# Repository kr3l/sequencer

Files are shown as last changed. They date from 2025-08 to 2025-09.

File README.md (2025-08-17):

ESP32 + TL074

the TL074 opamp is fed with -12 and +12V

GPIO25 -> pin3 of opamp
5.6kOhm + 1kOhm precision trimmer between pin 1 and 2 of opamp (feedback resistor)
10kOhm resistor between pin 2 and GND
-> opamp gain 1 + 5.6/10 -> 1.56
-> output max goes from 3.3V to 5.148V

100nF between pin 1 and GND

precision trimmer calibrated so the max outputted voltage on DAC results in exactly 5V

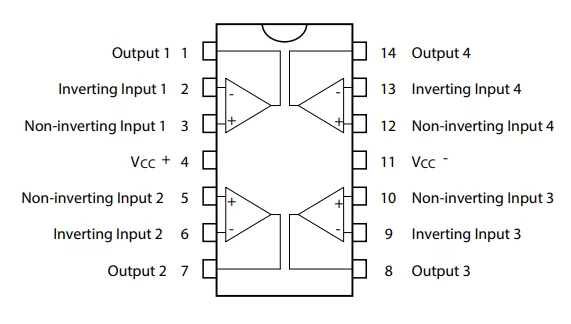
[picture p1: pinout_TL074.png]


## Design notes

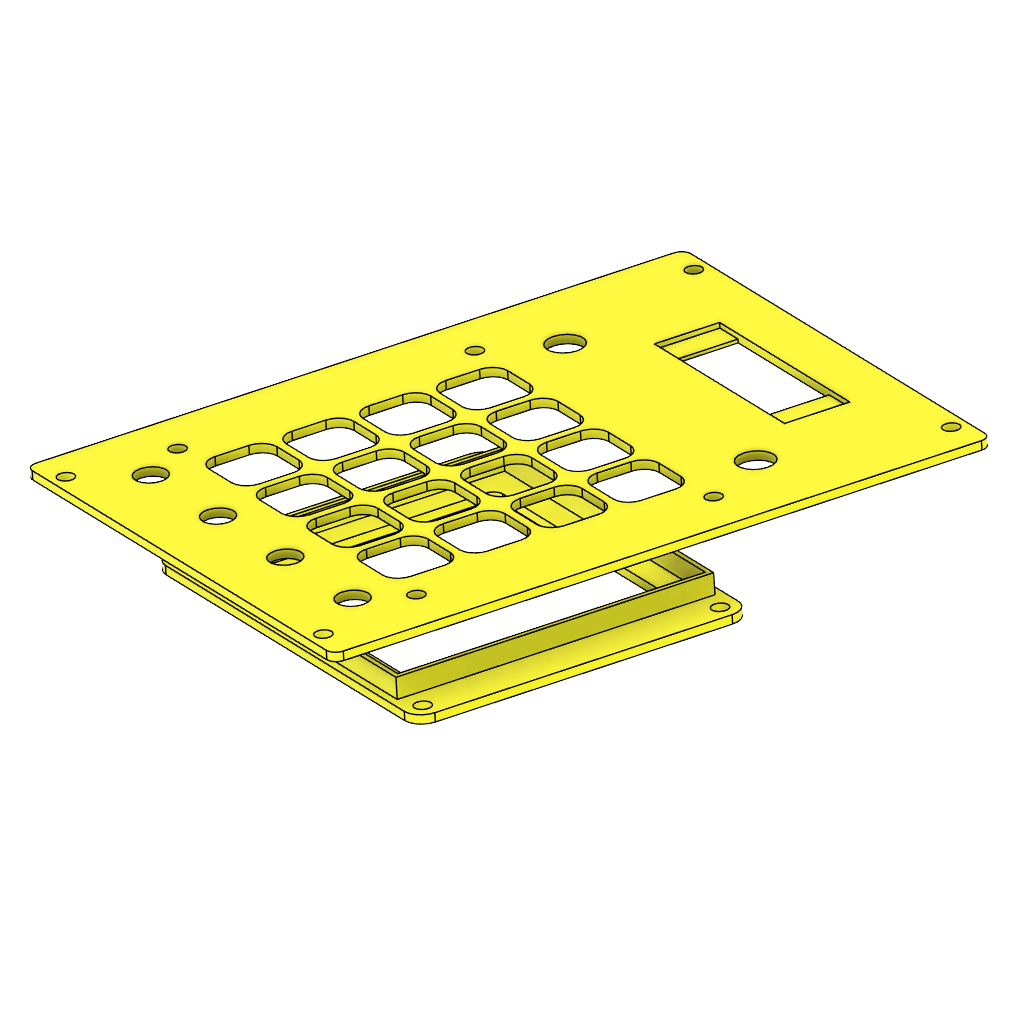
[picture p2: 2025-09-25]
cad/sequencer-neotrellis-eurorack v12.png

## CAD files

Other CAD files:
cad/sequencer-neotrellis v3.f3z
cad/sequencer-neotrellis v7.f3z
cad/sequencer-neotrellis-eurorack v11.f3z

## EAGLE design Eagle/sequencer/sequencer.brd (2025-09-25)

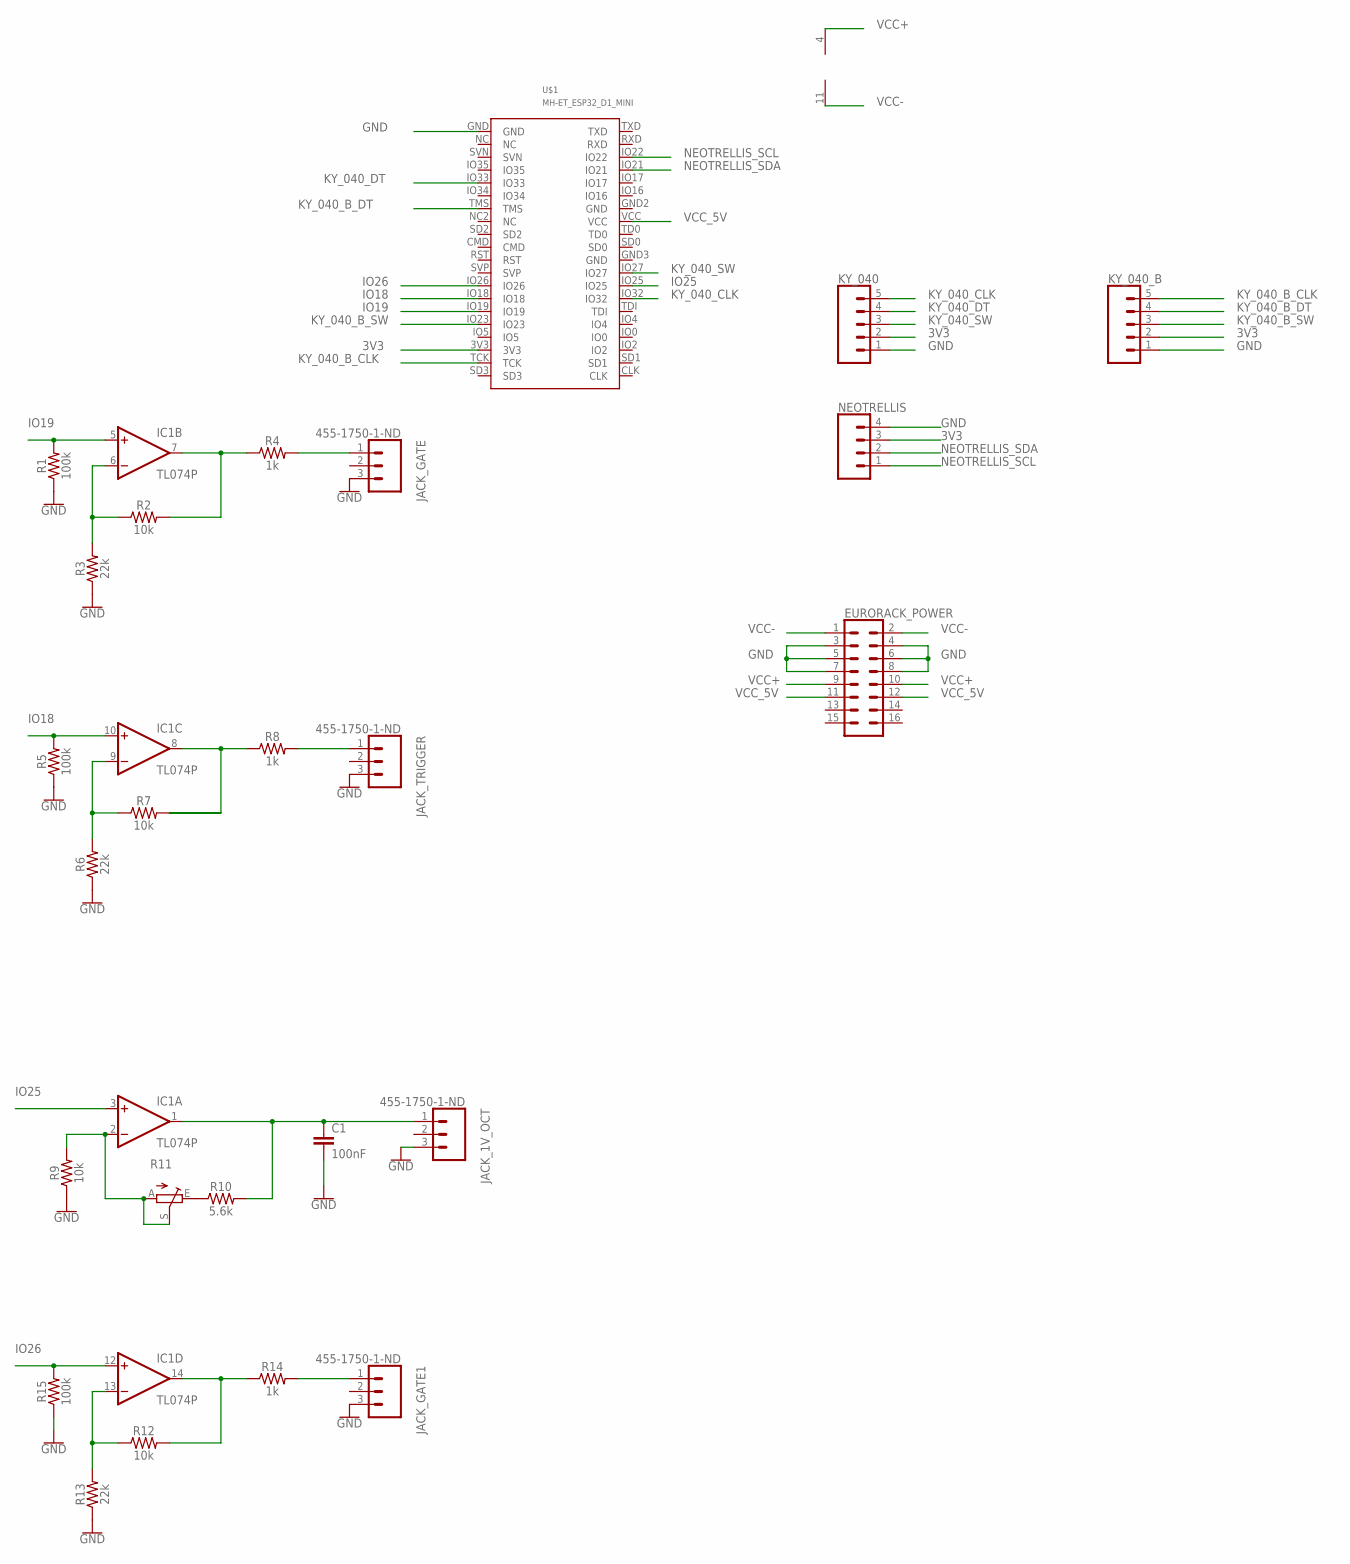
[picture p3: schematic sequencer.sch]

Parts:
C1: 100nF; C050-035X075
EURORACK_POWER: CONN_08X2_SHROUD; 2X8-SHROUDED_LOCK
IC1: TL074P; DIL14
JACK_1V_OCT: 455-1750-1-ND; 1X03
JACK_GATE, JACK_GATE1: 455-1750-1-ND; 1X03
JACK_TRIGGER: 455-1750-1-ND; 1X03
KY_040, KY_040_B: CONN_05; 1X05
NEOTRELLIS: CONN_04PTH; 1X04
R1, R5, R15: 100k; AXIAL-0.1
R2, R7, R9, R12: 10k; AXIAL-0.1
R3, R6, R13: 22k; AXIAL-0.1
R4, R8, R14: 1k; AXIAL-0.1
R10: 5.6k; AXIAL-0.1
R11: TRIM_EU-B64W; B64W
U$1: MH-ET_ESP32_D1_MINI

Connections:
3V3: KY_040.2, KY_040_B.2, NEOTRELLIS.3, U$1.3V3
GND: C1.2, EURORACK_POWER.3, EURORACK_POWER.4, EURORACK_POWER.5, EURORACK_POWER.6, EURORACK_POWER.7, EURORACK_POWER.8, JACK_1V_OCT.3, JACK_GATE.3, JACK_GATE1.3, JACK_TRIGGER.3, KY_040.1, KY_040_B.1, NEOTRELLIS.4, R1.P$1 (1), R3.P$1 (1), R5.P$1 (1), R6.P$1 (1), R9.P$1 (1), R13.P$1 (1), R15.P$1 (1), U$1.GND
IO18: IC1.10 (+IN), R5.P$2 (2), U$1.IO18
IO19: IC1.5 (+IN), R1.P$2 (2), U$1.IO19
IO25: IC1.3 (+IN), U$1.IO25
IO26: IC1.12 (+IN), R15.P$2 (2), U$1.IO26
KY_040_B_CLK: KY_040_B.5, U$1.TCK
KY_040_B_DT: KY_040_B.4, U$1.TMS
KY_040_B_SW: KY_040_B.3, U$1.IO23
KY_040_CLK: KY_040.5, U$1.IO32
KY_040_DT: KY_040.4, U$1.IO33
KY_040_SW: KY_040.3, U$1.IO27
unnamed: IC1.6 (-IN), R2.P$1 (1), R3.P$2 (2)
unnamed: IC1.7 (OUT), R2.P$2 (2), R4.P$1 (1)
unnamed: JACK_GATE.1, R4.P$2 (2)
unnamed: IC1.9 (-IN), R6.P$2 (2), R7.P$1 (1)
unnamed: IC1.8 (OUT), R8.P$1 (1)
unnamed: JACK_TRIGGER.1, R8.P$2 (2)
unnamed: IC1.13 (-IN), R12.P$1 (1), R13.P$2 (2)
unnamed: C1.1, IC1.1 (OUT), JACK_1V_OCT.1, R10.P$2 (2)
unnamed: R10.P$1 (1), R11.E
unnamed: IC1.2 (-IN), R9.P$2 (2), R11.A, R11.S
unnamed: IC1.14 (OUT), R12.P$2 (2), R14.P$1 (1)
unnamed: JACK_GATE1.1, R14.P$2 (2)
NEOTRELLIS_SCL: NEOTRELLIS.1, U$1.IO22
NEOTRELLIS_SDA: NEOTRELLIS.2, U$1.IO21
VCC+: EURORACK_POWER.9, EURORACK_POWER.10, IC1.4 (V+)
VCC-: EURORACK_POWER.1, EURORACK_POWER.2, IC1.11 (V-)
VCC_5V: EURORACK_POWER.11, EURORACK_POWER.12, U$1.VCC

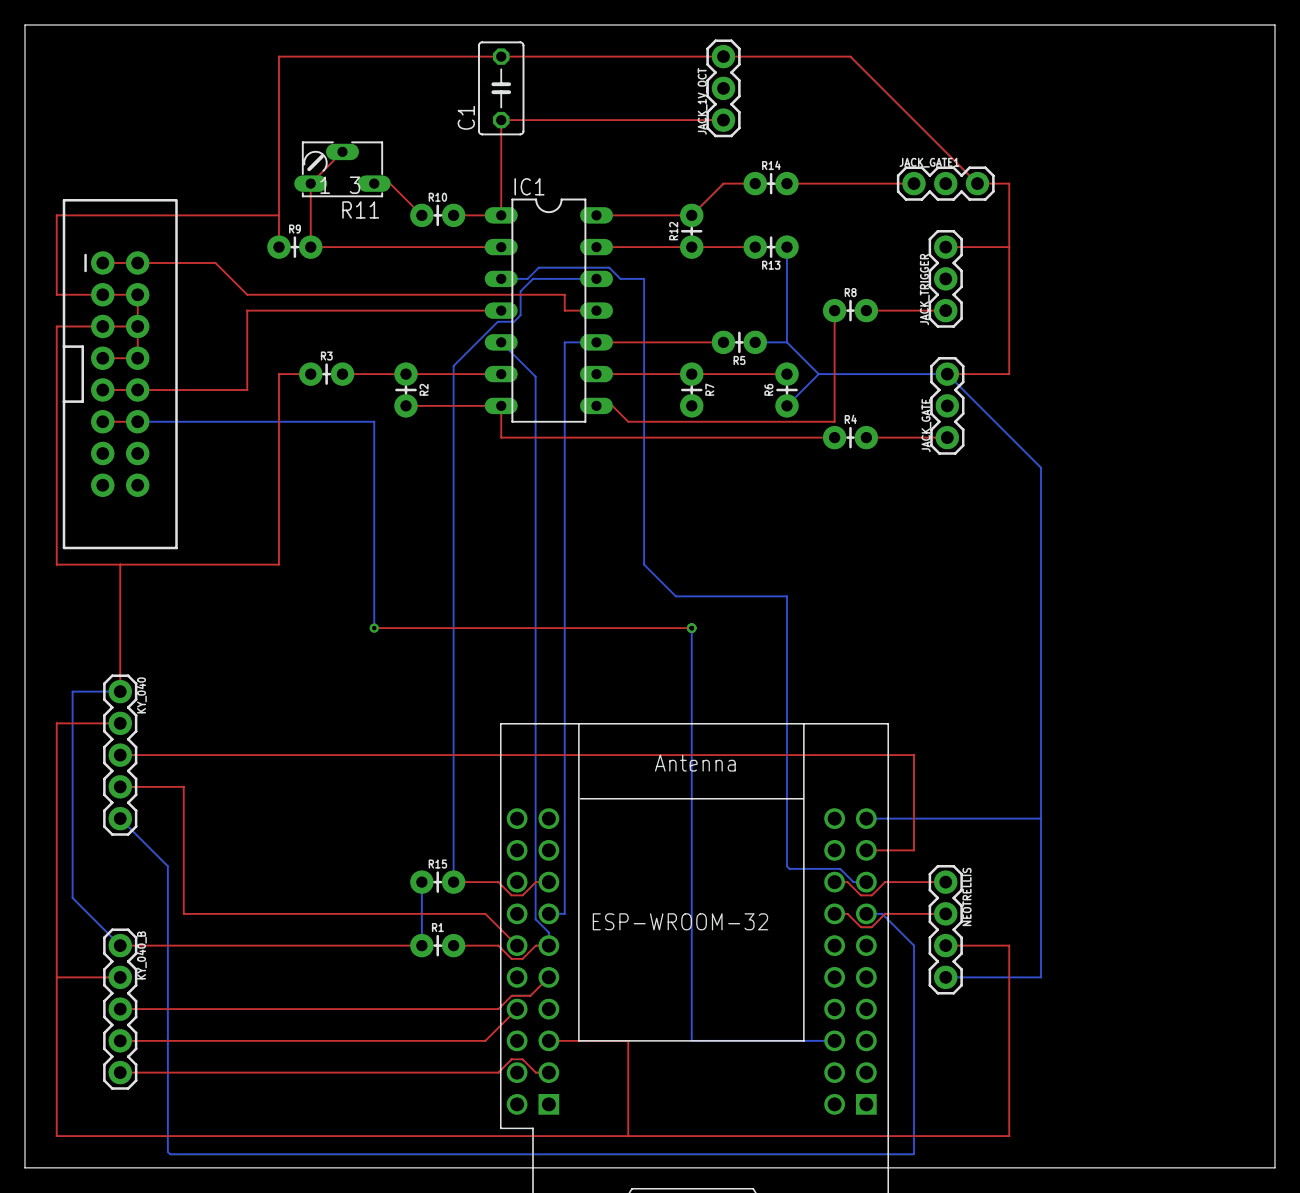
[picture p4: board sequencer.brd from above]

Board: 2 copper layers, 100.0 x 91.4 mm, 26 parts (0 on the bottom side), 29 nets.

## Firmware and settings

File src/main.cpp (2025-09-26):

#include <Arduino.h>
#include <Wire.h>
#include "NotePlayer.h"
#include "TrellisPad.h"
#include "Player.h"
#include "Melodies.h"
#include <ESP32Encoder.h>
#include <Preferences.h>

// OLED libs
#include <Adafruit_GFX.h>
#include <Adafruit_SSD1306.h>

// OLED pins
#define OLED_SDA SDA
#define OLED_SCL SCL
#define OLED_RST -1
#define SCREEN_WIDTH 128
#define SCREEN_HEIGHT 32

Preferences prefs;

// Create an Adafruit_SSD1306 object called display.
Adafruit_SSD1306 display(SCREEN_WIDTH, SCREEN_HEIGHT, &Wire, OLED_RST);

bool isProgramming[16];

//const int potPin = 36; // GPIO36 = ADC1_CH0 on ESP32 D1 mini
const int gatePin = 19;
const int triggerPin = 18;

NotePlayer notePlayer = NotePlayer(25); // GPIO25 supports DAC on ESP32
TrellisPad trellisPad = TrellisPad();
Player player = Player(&trellisPad, &notePlayer, 12, gatePin, triggerPin);

ESP32Encoder knobLeft;
ESP32Encoder knobRight;

enum EditMode {
    MODE_PITCH,
    MODE_DUTY,
    MODE_VELOCITY,
    MODE_STEPCOUNT,
};
const u_int8_t NUM_MODES = 4;
EditMode currentMode = MODE_PITCH;
EditMode previousMode = MODE_DUTY; // just so we trigger a change initially

// the last row of pads on neotrellis are reserved for functions
// and are not playable pads
int playButtonNumber = 12;
int modeButtonNumber = 13;

unsigned long minSlotDurationMs = 50;
unsigned long maxSlotDurationMs = 4000;

void setupDisplay() {
  // The parameters set as false ensure that the library doesn’t 
  // use the default I2C pins and use the pins defined in the code (GPIO 4 and GPIO 15).
  if (!display.begin(SSD1306_SWITCHCAPVCC, 0x3c, false, false)) {
    // address 0x3C for 128x32
    Serial.println(F("SSD1306 allocation failed"));
    for(;;); // Don't proceed, loop forever
  }
  // flip 180deg
  display.setRotation(2);
  display.clearDisplay();
  display.setTextColor(WHITE);
  display.setTextSize(2);
  display.setCursor(0,0);
  display.print("SEQUENCER");
  display.display();
}

int getKnobLeftCount() {
  int count = -(int32_t)knobLeft.getCount();
  return constrain(count, 0, 256);
}

int getKnobRightCount() {
  int count = -(int32_t)knobRight.getCount();
  return constrain(count, 0, 256);
}

void onLongPress(int x, int y) {
  int idx = y * 4 + x;
  if (player.steps[idx].isProgramming) {
    Serial.print("Stop Programming slot ");
  } else {
    Serial.print("Start Programming slot ");
  }
  Serial.println(idx);
  // Enter or leave programming mode (start blinking)
  player.steps[idx].isProgramming = !player.steps[idx].isProgramming;
  trellisPad.setBlinking(idx, player.steps[idx].isProgramming);
  trellisPad.lastBlink[idx] = millis();
  trellisPad.ledState[idx] = false;  // start off
}

void savePotToStep(int idx) {
    // short press to confirm writing pot value to slot idx
    int raw = getKnobLeftCount(); // read raw ADC value
    // Map raw value (0–4095) to percentage
    float dacOut =  ((float)raw / 255.0f) * notePlayer.dacOutMax;

    // autotune to nearest note
    dacOut = notePlayer.autotune(dacOut);

    player.steps[idx].programmedValue = dacOut;
    player.steps[idx].isProgramming = false;
    trellisPad.setBlinking(idx, false);
    Serial.print("Programmed slot ");
    Serial.println(idx);
    Serial.print("to value ");
    Serial.println(dacOut);
    trellisPad.trellis->pixels.setPixelColor(idx, 0x000000); // off
}

void onShortPress(int x, int y) {
  int idx = y * 4 + x;
  Serial.print("Short press detected on button ");
  Serial.println(idx);

  if (idx == modeButtonNumber) {
    currentMode = (EditMode)((currentMode + 1) % NUM_MODES);
    Serial.print("Set mode=");
    Serial.println(currentMode);
  }
  if (idx == playButtonNumber) {
    player.isPlayingSequence = !player.isPlayingSequence;
    
    if (player.isPlayingSequence) {
      player.playSlot(0);
      Serial.println("Play!");
      trellisPad.trellis->pixels.setPixelColor(playButtonNumber, 0xff1493); // on
    } else {
      Serial.println("Stop!");
      trellisPad.trellis->pixels.setPixelColor(playButtonNumber, 0x000000); // off
    }
  }

  if (idx >= player.numberOfPlayableSteps) {
    return;
  }

  if (player.steps[idx].isProgramming) {
    savePotToStep(idx);
  } else {
    // short press to turn gate on or off
    player.steps[idx].gateOn = !player.steps[idx].gateOn;
    // TODO: light led too, but dimmed
    // short press to request play note of slox idx
    //player.playSlot(idx);
  }
}


void saveData() {
  prefs.begin("storage", false);

  // read first so we can check if anything really changed
  float pitchR[16] = {0};
  bool gateOnR[16] = {true};
  uint8_t dutyR[16] = {100};
  size_t pitchBytesRead = prefs.getBytes("pitch", pitchR, sizeof(pitchR));
  size_t gateOnBytesRead = prefs.getBytes("gateOn", gateOnR, sizeof(gateOnR));
  size_t dutyBytesRead = prefs.getBytes("duty", dutyR, sizeof(dutyR));

  unsigned long stepDurationMsR = prefs.getULong("stepDurationMs", 0);
  int stepCountR = prefs.getInt("stepCount", 12);


  float pitch[16] = {0};
  bool gateOn[16] = {true};
  uint8_t duty[16] = {100};
  bool pitchChanged = (pitchBytesRead != sizeof(pitchR));
  bool gateOnChanged = (gateOnBytesRead != sizeof(gateOn));
  bool dutyChanged = (dutyBytesRead != sizeof(dutyR));
  for (int i = 0; i < 16; i += 1) {
    pitch[i] = player.steps[i].programmedValue;
    if (pitch[i] != pitchR[i]) {
      pitchChanged = true;
    }
    gateOn[i] = player.steps[i].gateOn;
    if (gateOn[i] != gateOnR[i]) {
      gateOnChanged = true;
    }
    duty[i] = player.steps[i].duty;
    if (duty[i] != dutyR[i]) {
      dutyChanged = true;
    }
  }

  // compare read version with what we want to write. Bail if exactly the same


  if (pitchChanged) {
    prefs.putBytes("pitch", pitch, sizeof(pitch));
    Serial.println("Pitch saved");
  }
  if (gateOnChanged) {
    prefs.putBytes("gateOn", gateOn, sizeof(gateOn));
    Serial.println("GateOn saved");
  }
  if (dutyChanged) {
    prefs.putBytes("duty", duty, sizeof(duty));
    Serial.println("Duty saved");
  }
  if (stepDurationMsR != player.stepDurationMs) {
    prefs.putULong("stepDurationMs", player.stepDurationMs);
    Serial.println("Tempo saved");
  }
  if (stepCountR != player.numberOfPlayableSteps) {
    prefs.putInt("stepCount", player.numberOfPlayableSteps);
    Serial.println("Step count saved");
  }
  
  prefs.end();
}

void loadData() {
  prefs.begin("storage", true);

  float pitch[16] = {0};
  bool gateOn[16] = {true};
  uint8_t duty[16] = {100};
  size_t pitchBytesRead = prefs.getBytes("pitch", pitch, sizeof(pitch));
  size_t gateOnBytesRead = prefs.getBytes("gateOn", gateOn, sizeof(gateOn));
  size_t dutyBytesRead = prefs.getBytes("duty", duty, sizeof(duty));
  unsigned long stepDurationMsR = prefs.getULong("stepDurationMs", player.stepDurationMs);
  int stepCountR = prefs.getInt("stepCount", 12);

  if (
    (pitchBytesRead != sizeof(pitch))
    || (gateOnBytesRead != sizeof(gateOn))
    || (dutyBytesRead != sizeof(duty))
  ) {
    prefs.end();
     Serial.println("No prefs found");
    return;
  }

  for (int i = 0; i < 16; i += 1) {
    player.steps[i].programmedValue = pitch[i];
    player.steps[i].gateOn = gateOn[i];
    player.steps[i].duty = duty[i];
  }
  player.stepDurationMs = stepDurationMsR;
  player.numberOfPlayableSteps = stepCountR;

  prefs.end();
  Serial.println("Prefs loaded");
}

void setup() {
  Serial.begin(115200);

  Serial.print("Using I2C at SDA=");
  Serial.print(SDA);
  Serial.print(", SCL=");
  Serial.println(SCL);
  Wire.begin(SDA, SCL);
  Wire.setClock(100000);

  setupDisplay();


  Serial.println("Send note name (e.g., C4, D#3), or 'off' to stop.");
  analogReadResolution(12); // 12-bit: 0–4095
  analogSetAttenuation(ADC_11db); // for input range up to ~3.3V

  trellisPad.setup();
  trellisPad.setShortPressCallback(onShortPress);
  // trellisPad.setLongPressCallback(onLongPress);

  //ESP32Encoder::useInternalWeakPullResistors = puType::down;
	// Enable the weak pull up resistors
	ESP32Encoder::useInternalWeakPullResistors = puType::up;
  knobLeft.attachSingleEdge(32, 33);
  knobRight.attachSingleEdge(13, 14);
  knobLeft.setFilter(1023);
  knobRight.setFilter(1023);

  // clear the encoder's raw count and set the tracked count to zero
	knobLeft.clearCount();
  knobRight.clearCount();
	Serial.println("knobLeft Start = " + String((int32_t)knobLeft.getCount()));
  Serial.println("knobRight Start = " + String((int32_t)knobRight.getCount()));

  loadData();
}

bool wasPressed[16] = {false};
String line1 = "";
String line2 = "";
int previousDisplayedNoteNum = -1;
float previousDisplayedDuty = -1;
unsigned long previousDisplayedTempo = 0;
int previousDisplayedStepCount = -1;

void printLines() {
  display.clearDisplay();
  display.setCursor(0,0);
  display.println(line1);
  display.setTextSize(1);
  display.setCursor(0,20);
  display.print(line2);
  display.display();
}

void loop() {
  unsigned long now = millis();

  trellisPad.loop();

  uint32_t outColor = 0xFF0000;

  // each led outputs the color corresponding to programmed value with low brightness
  // by default. This can be overwritten by following code, before pixels.show() is called.
  for (int i = 0; i < 12; i ++) {
    player.updateColorForStep(i);
  }

  if (currentMode != previousMode) {
    display.clearDisplay();
    display.setTextSize(2);
    display.setCursor(0,0);
    display.cp437(true);         // Use full 256 char 'Code Page 437' font
    if (currentMode == MODE_PITCH) {
      line1 = "PITCH";
    } else if (currentMode == MODE_DUTY) {
      line1 = "DUTY";
    } else if (currentMode == MODE_VELOCITY) {
      line1 = "TEMPO";
    } else if (currentMode == MODE_STEPCOUNT) {
      line1 = "STEP COUNT";
    }
    printLines();
  }

  // turning the pot while holding down a pad sets the pitch of that step
  if (currentMode == MODE_PITCH) {
    for (int i = 0; i < player.numberOfPlayableSteps; i++) {
      if (!trellisPad.isPressed[i]) {
        if (wasPressed[i]) {
          saveData();
        }
        continue;
      }

      // this is the first loop iteration this button is pressed after being unpressed
      // restore the count as stored in programmed value so we change from there
      if (!wasPressed[i]) {  
        if (notePlayer.autotuneActive) {
          float prevNoteNum = player.steps[i].programmedValue;
          int prevKnobLeftCount = -(int)(prevNoteNum);
          knobLeft.setCount(prevKnobLeftCount);
        } else {
          float prevDac = player.steps[i].programmedValue;
          int prevKnobLeftCount = -(int)(prevDac * 255.0f / notePlayer.dacOutMax);
          knobLeft.setCount(prevKnobLeftCount);
        }
      }
      int raw = getKnobLeftCount(); // read encoder
      float dacOut;
      int noteNum;
      if (notePlayer.autotuneActive) {
        noteNum = constrain(raw, 0, NotePlayer::numNotes - 1);
        float freqOut = NotePlayer::noteTable[noteNum].frequency;
        dacOut = notePlayer.frequencyToDacVoltage(freqOut);
        
        // program value immediately
        player.steps[i].programmedValue = noteNum;
      } else {
        // Map raw value (255) to note number
        dacOut =  ((float)raw / 255.0f) * notePlayer.dacOutMax;
        // dacOut = notePlayer.autotune(dacOut);

        // program value immediately
        player.steps[i].programmedValue = dacOut;
      }

      // preview value by playing it out
      notePlayer.setDacOutVoltage(dacOut);

      // also light led with color corresponding to dacOut
      byte out = (byte) round((dacOut / notePlayer.dacOutMax) * 255.0);
      outColor = trellisPad.Wheel(out);
      trellisPad.trellis->pixels.setPixelColor(i, outColor);

      // display value
      if (notePlayer.autotuneActive && (noteNum != previousDisplayedNoteNum)) {
        line2 = "";
        line2 += NotePlayer::noteTable[noteNum].name;
        line2 += " / ";
        line2 += dacOut;
        line2 += "V";
        previousDisplayedNoteNum = noteNum;
        printLines();
      }


      // only the first pressed pad is set
      break;
    }
  }

  if (currentMode == MODE_DUTY) {
    for (int i = 0; i < player.numberOfPlayableSteps; i++) {
      if (!trellisPad.isPressed[i]) {
        if (wasPressed[i]) {
          saveData();
        }
        continue;
      }

      // start from previous value
      if (!wasPressed[i]) {  
        uint8_t prev = player.steps[i].duty;
        int prevKnobLeftCount = -(int)(prev * 255.0f / 100.0);
        knobLeft.setCount(prevKnobLeftCount);
      }

      int raw = getKnobLeftCount(); // read raw ADC value
      // Map raw value (0–4095) to percentage 0..100
      float duty =  ((float)raw / 255.0f) * 100.0;

      // program value immediately
      player.steps[i].duty = (uint8_t)duty;

      // also light led with color corresponding to percentage
      // (note: blinking seems more common preview)
      byte out = (byte) round((duty / 100.0) * 255.0);
      outColor = trellisPad.Wheel(out);
      trellisPad.trellis->pixels.setPixelColor(i, outColor);

      // display value
      if (duty != previousDisplayedDuty) {
        line2 = "";
        line2 += duty;
        line2 += "%";
        previousDisplayedDuty = duty;
        printLines();
      }

      // only the first pressed pad is set
      break;
    }
  }

  if (currentMode == MODE_VELOCITY) {
    if (previousMode != currentMode) {
      unsigned long prev = player.stepDurationMs;
      int prevKnobLeftCount = -(int)(prev * 255.0 / ((float)maxSlotDurationMs));
      knobLeft.setCount(prevKnobLeftCount);
    }
    int raw = getKnobLeftCount(); // read raw ADC value
    player.stepDurationMs = (float)raw * (float)maxSlotDurationMs / 255.0f;
    if (player.stepDurationMs < minSlotDurationMs) {
      player.stepDurationMs = minSlotDurationMs;
    }

    // display value
    if (player.stepDurationMs != previousDisplayedTempo) {
      int bpm = 0;
      if (player.stepDurationMs > 0) {
        bpm  = (int)(60000.0 / player.stepDurationMs);
      }
      line2 = "";
      line2 += player.stepDurationMs;
      line2 += "ms/step";
      line2 += "  ";
      line2 += bpm;
      line2 += "bpm";
      previousDisplayedTempo = player.stepDurationMs;
      printLines();
    }
  }

  if (currentMode == MODE_STEPCOUNT) {
    if (previousMode != currentMode) {
      int prev = player.numberOfPlayableSteps;
      int prevKnobLeftCount = -prev;
      knobLeft.setCount(prevKnobLeftCount);
    }

    int raw = getKnobLeftCount();
    player.numberOfPlayableSteps = constrain(raw, 1, 12);

    // display value
    if (player.numberOfPlayableSteps != previousDisplayedStepCount) {
      line2 = "";
      line2 += player.numberOfPlayableSteps;
      line2 += " steps";
      previousDisplayedStepCount = player.numberOfPlayableSteps;
      printLines();
    }
  }

  if (previousMode != currentMode) {
    saveData();
    line2 = "";
    printLines();
  }

  previousMode = currentMode;
  for (int i = 0; i < player.numberOfPlayableSteps; i ++) {
    wasPressed[i] = trellisPad.isPressed[i];
  }

  player.loop();
  trellisPad.trellis->pixels.show();
  delay(20);
  if (!Serial.available()) {
    delay(50);
    return;
  }
  String input = Serial.readStringUntil('\n');
  input.trim();
  if (input.equalsIgnoreCase("off")) {
    notePlayer.setAmpOutVoltage(0);
    Serial.println("Output off.");
  } else if (input.equalsIgnoreCase("star")) {
    notePlayer.playMelody(melodyTwinkle, melodyTwinkleLength);
  } else if (input.equalsIgnoreCase("ode")) {
    notePlayer.playMelody(melodyOdeToJoy, melodyOdeToJoyLength, 400);
  } else if (input.equalsIgnoreCase("ateam")) {
    notePlayer.playMelody(melodyATeam, melodyATeamLength);
  } else if (input.equalsIgnoreCase("elise")) {
    notePlayer.playMelody(melodyFurElise, melodyFurEliseLength);
  } else if (input.equalsIgnoreCase("pot")) {
  } else {
    notePlayer.setNoteVoltage(input);
  }
}

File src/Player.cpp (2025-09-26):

#include "Arduino.h"
#include "Player.h"

Player::Player(TrellisPad *_trellisPad, NotePlayer *_notePlayer, int _numberOfPlayableSteps, int _gatePin, int _triggerPin) {
    trellisPad = _trellisPad;
    notePlayer = _notePlayer;
    isPlayingSequence = false;
    numberOfPlayableSteps = _numberOfPlayableSteps;
    stepDurationMs = 500;
    gatePin = _gatePin;
    triggerPin = _triggerPin;
    pinMode(gatePin, OUTPUT); 
    pinMode(triggerPin, OUTPUT); 

    for (int i=0; i<16; i+=1) {
        steps[i].programmedValue = 0.0f;
        steps[i].isProgramming = false;
        steps[i].duty = 100;
        steps[i].gateOn = true;
        // "now" properties relate to actual state (not programmed state)
        steps[i].nowPlaying = false;
        steps[i].nowPlayingSince = 0;
        steps[i].nowGateHigh = false;
        steps[i].writtenDac = false;
    }
}

void Player::stop(void) {
    int playSlotNumber = getPlayingStepNumber();
    if (playSlotNumber < 0) {
        return;
    }
    steps[playSlotNumber].nowPlaying = false;
    steps[playSlotNumber].nowPlayingSince = 0;
    steps[playSlotNumber].nowGateHigh = 0;
    steps[playSlotNumber].writtenDac = false;
    trellisPad->trellis->pixels.setPixelColor(playSlotNumber, 0x000000); // off
    Serial.print("Stop play slot ");
    Serial.println(playSlotNumber);
    //notePlayer->setDacOutVoltage(0.0);
}

void Player::playSlot(int idx) {
    stop();
    steps[idx].nowPlaying = true;
    steps[idx].nowPlayingSince = millis();
    if (steps[idx].duty > 0) {
        steps[idx].nowGateHigh = true;
    } else {
        steps[idx].nowGateHigh = false;
    }
    steps[idx].writtenDac = false;
    Serial.print("Play slot ");
    Serial.println(idx);
}

bool Player::isPlaying(void) {
    for (int i=0; i<16; i+=1) {
        if (steps[i].nowPlaying) {
            return true;
        }
    }
    return false;
}

int Player::getPlayingStepNumber(void) {
    for (int i=0; i<16; i+=1) {
        if (steps[i].nowPlaying) {
            return i;
        }
    }
    return -1;
}

void Player::updateColorForStep(int idx) {
    Step *step = &steps[idx];
    if (!step->gateOn || idx >= numberOfPlayableSteps) {
        trellisPad->trellis->pixels.setPixelColor(idx, 0x000000);
        return;
    }
    float dacOut = step->programmedValue;
    if (notePlayer->autotuneActive) {
        int noteNum = constrain(step->programmedValue, 0, NotePlayer::numNotes - 1);
        float freqOut = NotePlayer::noteTable[noteNum].frequency;
        dacOut = notePlayer->frequencyToDacVoltage(freqOut);
    }
    byte out = (byte) round((dacOut / notePlayer->dacOutMax) * 255.0);
    uint32_t outColor = 0xFF0000;
    if (step->nowPlaying) {
        outColor = trellisPad->Wheel(out);
    } else {
        outColor = trellisPad->Wheel(out, 255 / 6);
    }
    trellisPad->trellis->pixels.setPixelColor(idx, outColor);
}

void Player::loop(void) {
    int nowPlayingStepNumber = getPlayingStepNumber();
    if (nowPlayingStepNumber < 0) {
        return;
    }
    Step *step = &steps[nowPlayingStepNumber];
    if ((millis() - step->nowPlayingSince) > stepDurationMs) {
      int nextSlotNumber = (nowPlayingStepNumber + 1) % numberOfPlayableSteps;
      stop();
      if (isPlayingSequence) {
        // advance to next slot
        //Serial.print("move to step ");
        Serial.println(nextSlotNumber);
        playSlot(nextSlotNumber);
      } else {
         digitalWrite(gatePin, LOW);
      }
      return;
    }
    
    if (step->writtenDac) {
        unsigned long gateHighDuration = (unsigned long)((float)stepDurationMs * (float)steps[nowPlayingStepNumber].duty / 100.0);
        // trigger goes low immediately
        digitalWrite(triggerPin, LOW);
        if (step->nowGateHigh && (millis() - steps[nowPlayingStepNumber].nowPlayingSince) > gateHighDuration) {
            // lower the gate!
            // for now we don't have separate gate signal, we just clear dac
            //notePlayer->setDacOutVoltage(0.0); // TODO remove this line

            digitalWrite(gatePin, LOW);

            //Serial.println("lower gate");
            step->nowGateHigh = false;
        }

        return;
    }

    // start slot play
    float outValue = step->programmedValue;
    // for now we don't have separate gate signal, so we clear the dac if gate off
    if (step->gateOn) {
        //Serial.print("play step ");
        //Serial.print(nowPlayingStepNumber);
        if (notePlayer->autotuneActive) {
            int noteNum = constrain((int)outValue, 0, NotePlayer::numNotes - 1);
            float freqOut = NotePlayer::noteTable[noteNum].frequency;
            float dacOut = notePlayer->frequencyToDacVoltage(freqOut);
            notePlayer->setDacOutVoltage(dacOut);
        } else {
            notePlayer->setDacOutVoltage(outValue);
        }
        
        if (step->duty > 0) {
            digitalWrite(gatePin, HIGH);
            digitalWrite(triggerPin, HIGH);
        }
    } else {
        //Serial.print("play muted step ");
        //Serial.println(nowPlayingStepNumber);
        //notePlayer->setDacOutVoltage(0.0); // TODO remove this line
        digitalWrite(gatePin, LOW);
        digitalWrite(triggerPin, LOW);
    }
    
    step->writtenDac = true;
    Serial.printf("Dac Out: %.1f%V\n", outValue);
}

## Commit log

2025-08-17 add neotrellis, program notes
    [sketch_sequencer.fzz]
2025-08-17 fusion 360 round plate and tray
    [sequencer-neotrellis v3.f3z, sequencer-neotrellis v7.f3z]
2025-08-23 changed interface to a mode button, pitch, duty cycle, on/off can be set
2025-08-23 dim led when not active but programmed and gate on
2025-08-23 velocity mode + actually write gate and trigger outputs
2025-09-20 encoders instead of pot (untested)
2025-09-20 Revert "encoders instead of pot (untested)"
    This reverts commit 05debf08ba5b22f98a5a2d6460360932c0ab7ab3.
    [main.cpp]
2025-09-20 working with other encoder lib
2025-09-25 follow advise from library readme and set filter high
2025-09-25 when programming pitch value, start from previous value
2025-09-25 fix remember last tempo
    [main.cpp]
2025-09-25 cad files for eurorack panel sequencer
    [sequencer-neotrellis-eurorack v11.f3z]
2025-09-25 Eagle schematic and board layout
    [sequencer.brd, sequencer.sch]
2025-09-25 display, render mode and pitch
2025-09-26 let one encoder tick move up/down one note
2025-09-26 stepcount mode + playout fix
    [Player.cpp, main.cpp]
2025-09-26 now that we have gate and trigger, no longer set dac out to 0
    [Player.cpp]

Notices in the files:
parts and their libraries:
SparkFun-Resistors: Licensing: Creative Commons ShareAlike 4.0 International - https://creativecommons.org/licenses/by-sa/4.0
